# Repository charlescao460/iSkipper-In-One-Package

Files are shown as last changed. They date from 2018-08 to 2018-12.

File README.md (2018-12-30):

iSkipper-In-One-Package
=======================
An integration of Arduino and RFM69HW for an audience response system.
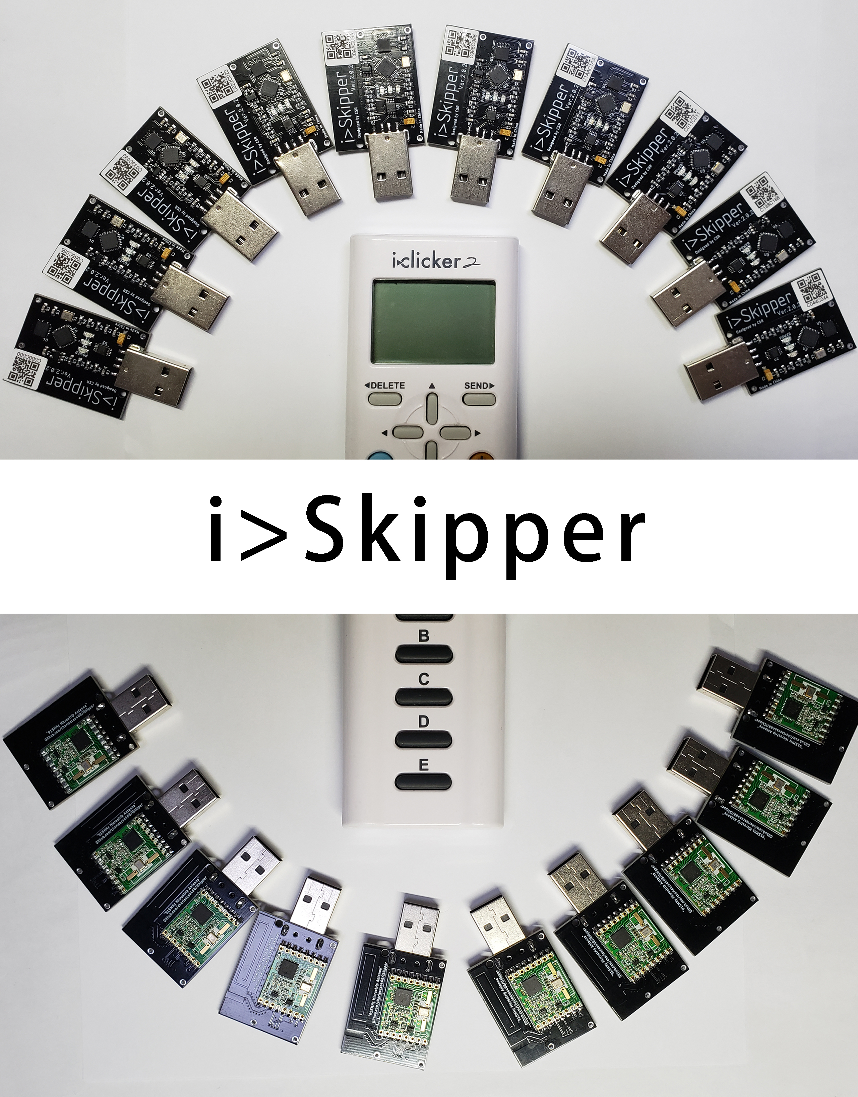
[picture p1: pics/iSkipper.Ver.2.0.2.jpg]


Versions
----
For the hardwares, there are currently two available versions: ***Ver.1.0.2*** and ***Ver.2.0.2***. (The Ver.1.0.0-1.0.1, Ver.2.0.0-2.0.1 are not perfectly useable).

The softwares should be compatible with all versions of hardwares.

### Ver.2.0.2
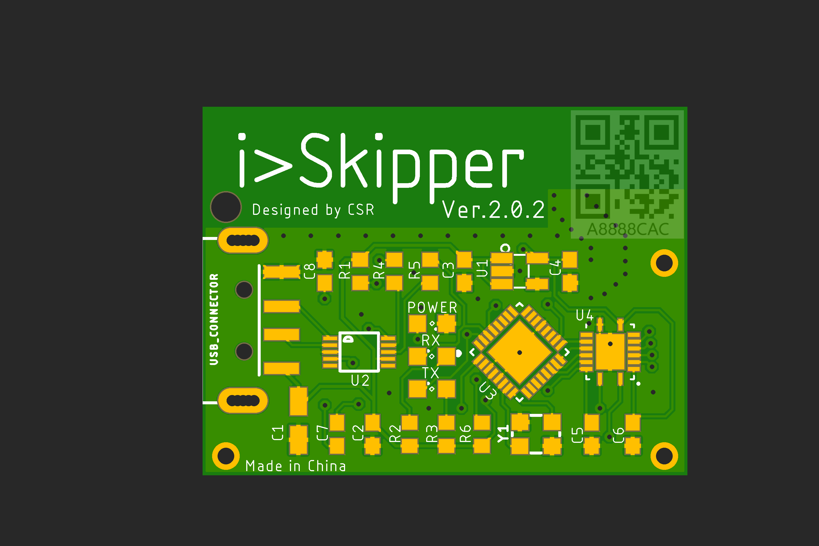
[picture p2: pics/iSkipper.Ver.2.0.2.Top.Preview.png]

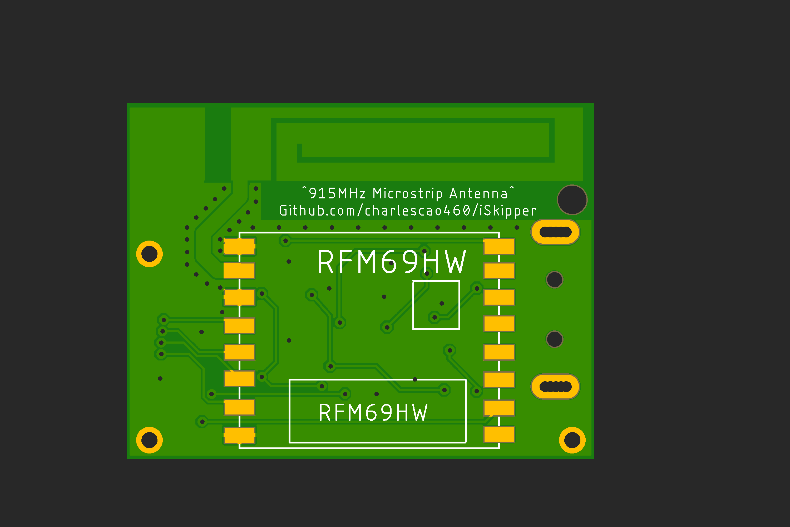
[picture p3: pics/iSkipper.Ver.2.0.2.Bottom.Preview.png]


**Size:** 50mm x 26mm (including USB connector), 35mm x 26mm (without USB connector)

**MCU:** ATmega328P-MU (QFN-32)

**USB to Serial:** CH340E (MSOP-10)

**RF:** RFM69HW

**Level-shifting:** TXB0106RGYR (VQFN-16)

**3.3V power supply:** LP5907MFX-3.3 (SOT23-5)

**Antenna:** patch antenna (theoretically 3dbi gain)

**Resistors/Capacitors:** 0603

The Ver.2.X.X version is designed to minimize board's size, maximize portability and invisibility. Thus, the possibly smallest packages are selected. For example, the patch antenna, QFN-packaged chips, 0603 Resistors/Capacitors are used. Although it still practicable to solder it manually, it would be hard to do so without solder paste. Besides, you would need to burn Arduino's bootloader into ATmega328P-MU before soldering. Burning bootloader would require a QFN-32 dock, or other additional cost.

There are four holes on the board reserved for case installing. If you are going to use screws to install Acrylic case, please notice that the metal screws near the patch antenna would influence antenna's performances.

### Ver.1.0.2
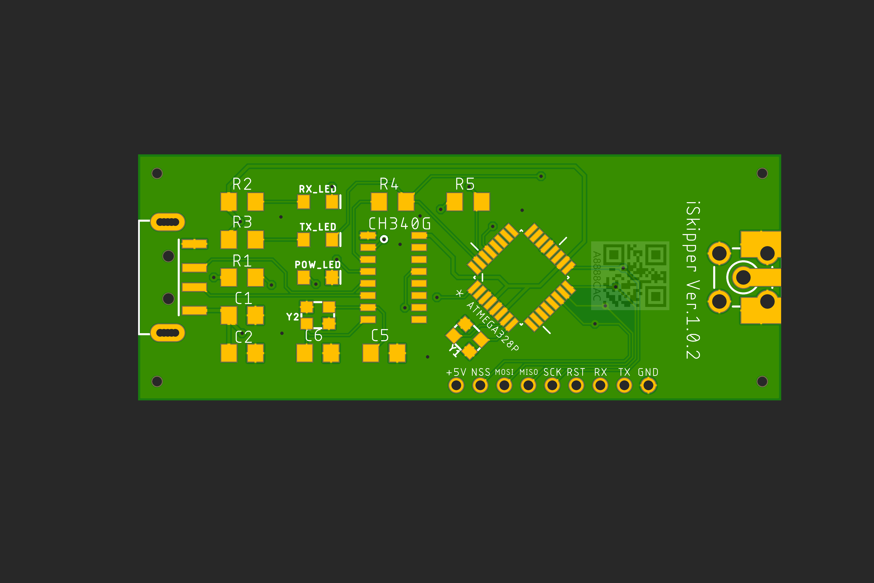
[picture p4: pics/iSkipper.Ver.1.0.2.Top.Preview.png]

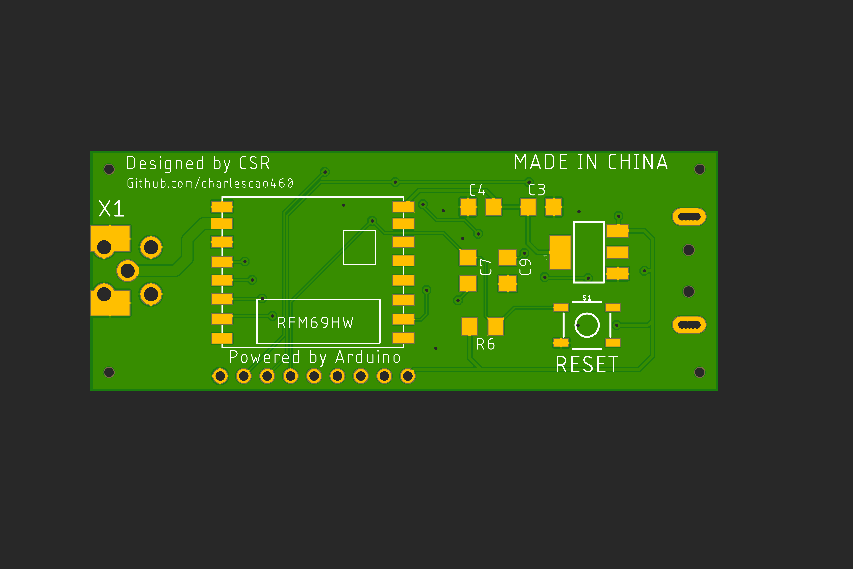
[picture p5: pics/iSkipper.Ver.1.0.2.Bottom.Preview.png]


**Size:** 90mm x 26mm (with connectors), 68mm x 26mm (without connectors)

**MCU:** ATmega328P-AU (QFP-32)

**USB to Serial:** CH340G (SOP-16)

**RF:** RFM69HW

**Level-shifting:** None (but it still work)

**3.3V power supply:** LM1117-3.3 (SOT223) (AMS1117 is also selectable)

**Antenna:** external antenna (with SMA connector)

**Resistors/Capacitors:** 1206

The Ver.1.X.X version is the first design of this project. It is basically a combination of Arduino Nano and RFM69HW. The original goal of this design is make it to be easy-manufactured. Thus, all components are big enough to solder with the normal soldering equipments and materials.

Some useful pin headers are reserved for burning bootloader or debugging. 

This version requires external antenna for better RF performance. The high-gain antennas would improve receiving performances. However, the overall size of this board would then be very big. (And if you are using this in public, the flaring LEDs and long antenna would catch everyone's eyes:) 

Notes
------
ATmega328P is working on 5 voltage, but RFM69HW requires 3.3 voltage. However, shockingly, they are stable and durable in daily use.

Update 2018/07/06: In Ver.2.0.0 design, I added a TXB0106 for level-shifting. So the logic level won't be a problem anymore. But I am still wondering why RFM69HW could work proper under 5.0V. To save money, you could still consider remove TXB0106 in your own disign. 

See also
--------
[iSkipper](https://github.com/wizard97/iSkipper) Original repository that inspired this project.

[iSkipper-Software](https://github.com/charlescao460/iSkipper-Software) 
The softwares (contains Arduino Sketch) designed for these boards.

Disclaimer
----------
**This project is only a special version of Arduino Nano.**

**THIS PROJECT IS NOT DESIGNED TO REPLACE, EMULATE, OR BE COMPATIBLE WITH ANY SPECIFIC PRODUCT OF ANY COMPANY.**

**ALL THE PICTURES AND DOCUMENTS OF THIS PROJECT DO NOT IMPLY ANY SPECIFIC USE OF THIS PROJECT.**

**CONTRIBUTORS OF THIS PROJECT ARE FREE OF RESPONSIBILITY OF ANY IMPROPER USE OF THIS PROJECT.**

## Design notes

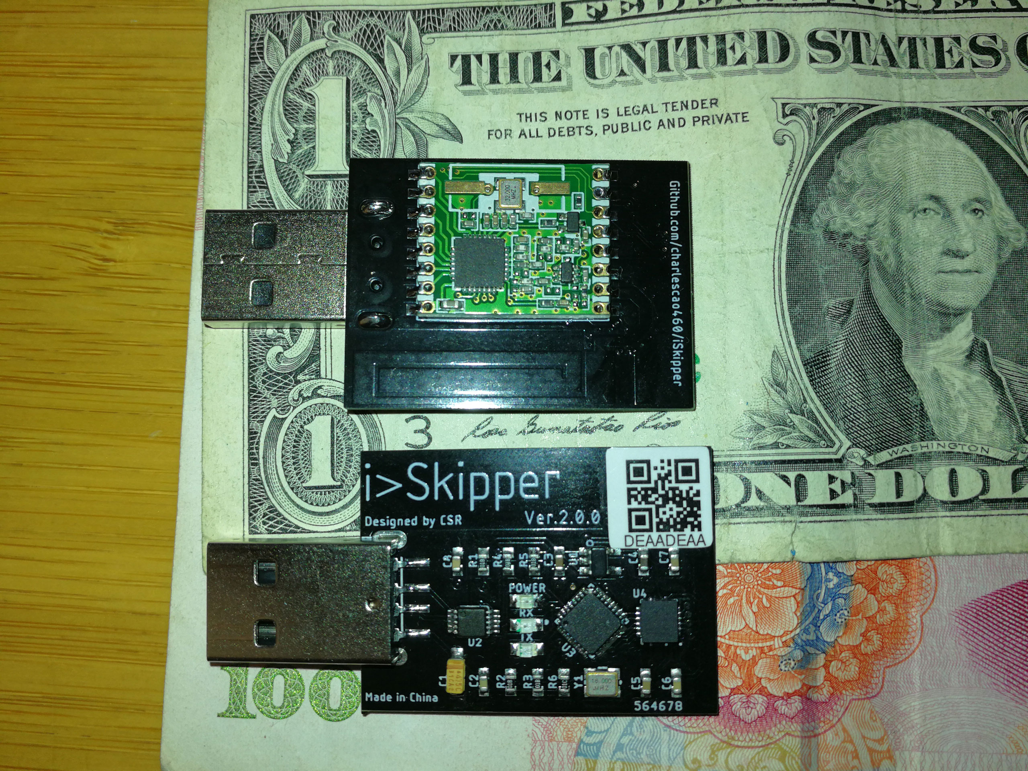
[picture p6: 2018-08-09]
pics/Ver2.0.0.Small.Size.jpg

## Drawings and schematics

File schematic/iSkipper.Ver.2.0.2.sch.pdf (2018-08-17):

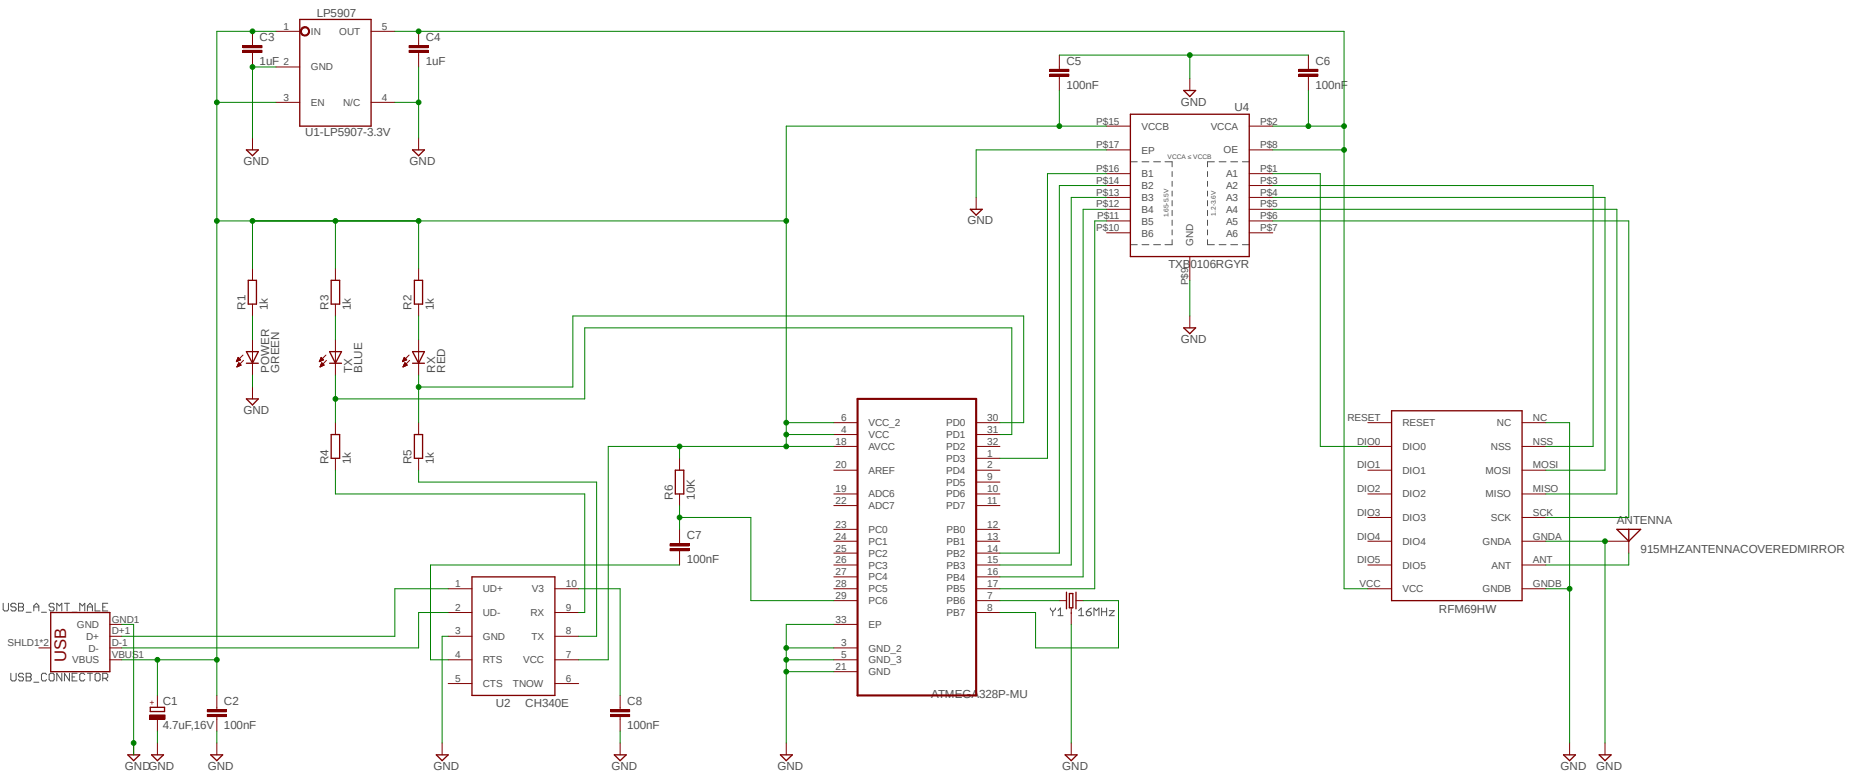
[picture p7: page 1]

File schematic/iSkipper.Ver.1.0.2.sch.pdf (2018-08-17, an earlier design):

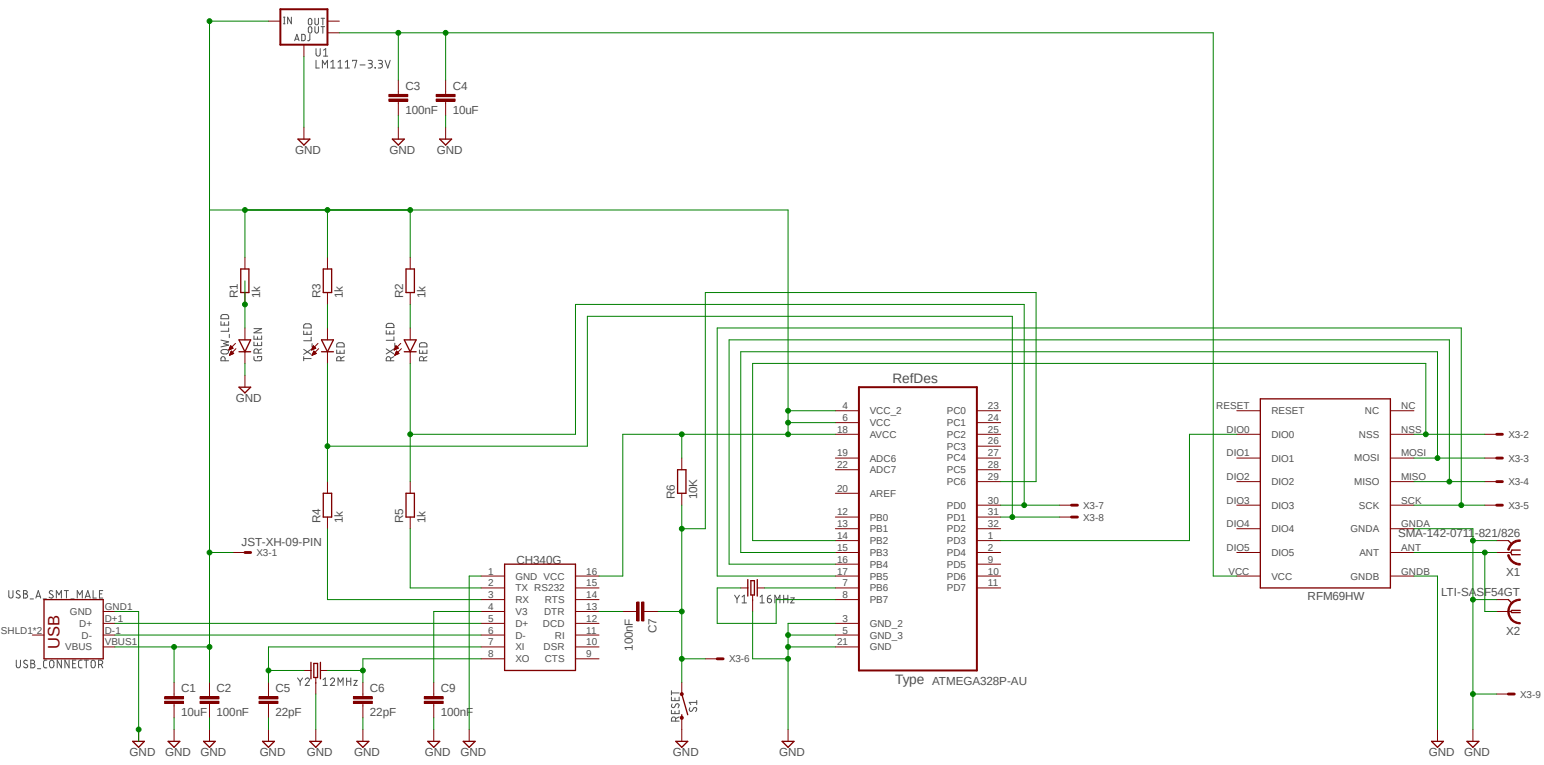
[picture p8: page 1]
Type ATMEGA328P-AU; GND GND GND; GND; GND¹k; RFM69HW ¹k; GND¹⁰K; GND GND; SMA-142-0711-821/826; LTI-SASF54GT; VCC_2 4 VCC 6 AVCC 18; ADC6 19 ADC7 22; AREF 20; GND_2 3 GND_3 5 GND 21; 11 RefDes; VBUS; VBUS1; GND1; SHLD1*2; GND 1 TX 2 RX 3 V3 4 D+ 5 D- 6 XI 7; CTS; DSR; 11 DCD; 12 DTR; 13 RTS; 15 VCC; RESET RESET; DIO0 DIO0; DIO1 DIO1; DIO2 DIO2; DIO3 DIO3; DIO4 DIO4; DIO5 DIO5; VCC VCC; GNDB; ANT; GNDA; SCK; MISO; MOSI; NSS; X3-9 USB

JST-XH-09-PIN

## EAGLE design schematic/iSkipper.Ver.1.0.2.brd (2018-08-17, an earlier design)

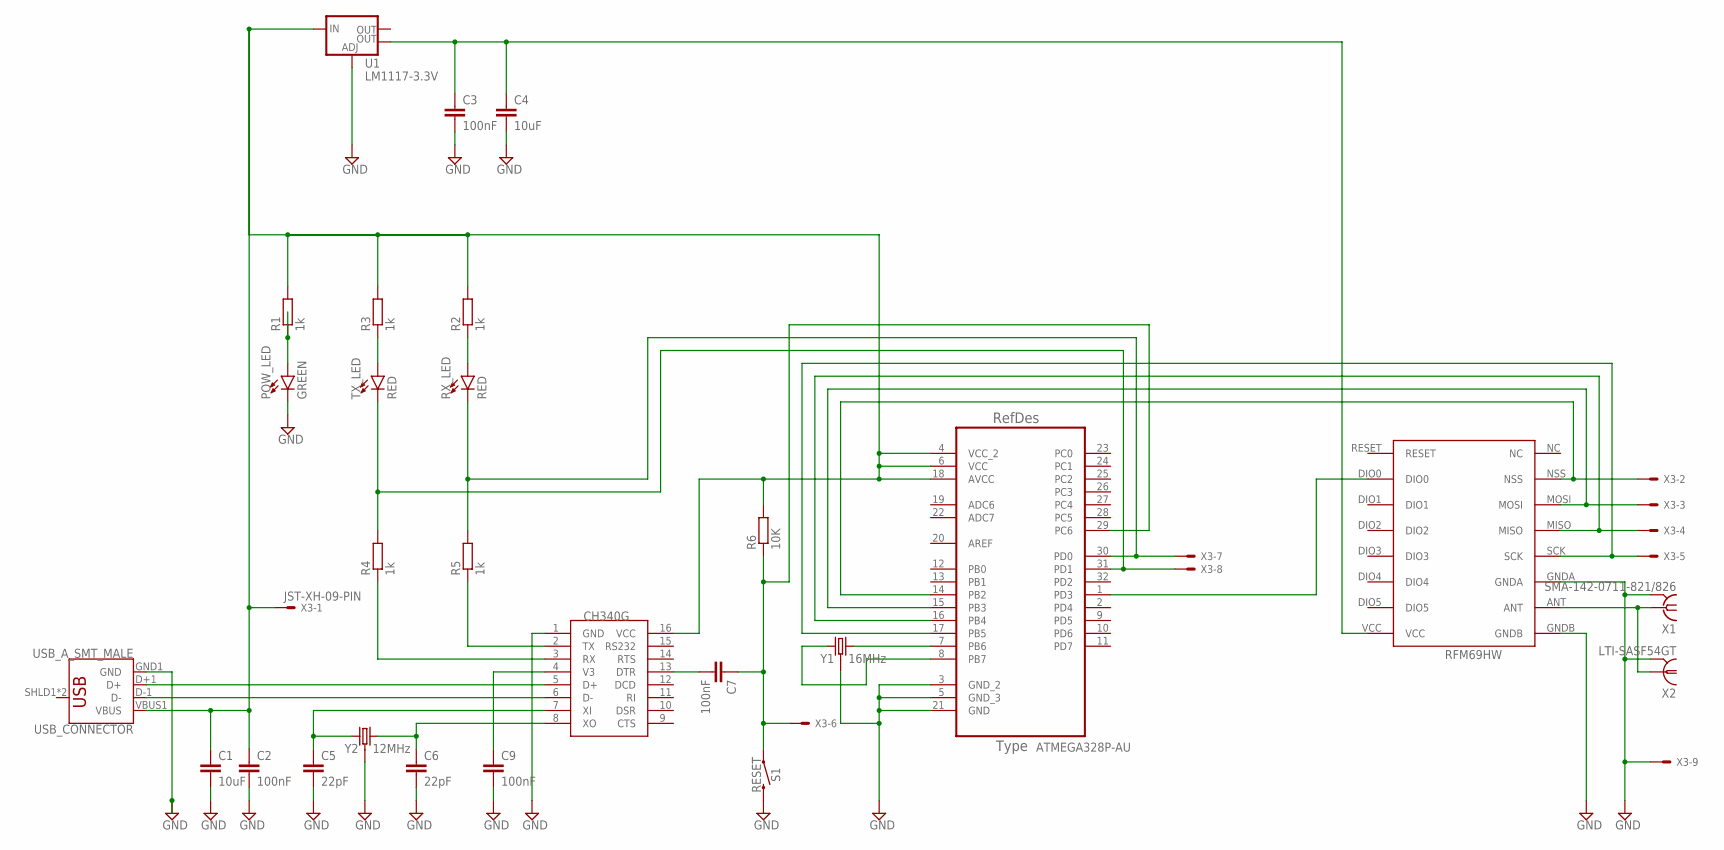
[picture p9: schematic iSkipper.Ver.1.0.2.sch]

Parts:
ATMEGA328P: ATMEGA328P-AU; QFP80P900X900X120-32N
C1, C4: 10uF; C1206
C2, C3, C7, C9: 100nF; C1206
C5, C6: 22pF; C1206
POW_LED: GREEN; LED-1206
R1, R2, R3, R4, R5: 1k; R1206
R6: 10K; R1206
RFM69HW: RFM69HW; RFM
RX_LED: RED; LED-1206
S1: RESET; TACTILE_SWITCH_SMD_5.2MM
TX_LED: RED; LED-1206
U1: LM1117-3.3V; SOT223
U$1: CH340G; SOIC16
USB_CONNECTOR: USB_A_SMT_MALE; USB-A-SMT-MALE
X1: SMA-142-0711-821/826; J502-ND-142-0711-821/826
X2: LTI-SASF54GT
X3: JST-XH-09-PIN; JST-XH-09-PACKAGE-ROUND-PAD-NO-SILK
Y1: 16MHz; CRYSTAL-SMD-3.2X2.5MM
Y2: 12MHz; CRYSTAL-SMD-3.2X2.5MM

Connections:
GND: ATMEGA328P.3 (GND_2), ATMEGA328P.5 (GND_3), ATMEGA328P.21 (GND), C1.2, C2.2, C3.2, C4.2, C5.2, C6.2, C9.2, POW_LED.C, RFM69HW.GNDA, RFM69HW.GNDB, S1.3 (2), U1.1 (ADJ), U$1.1 (GND), USB_CONNECTOR.GND1 (GND), X1.G@1 (2), X1.G@2 (2), X1.G@3 (2), X1.G@4 (2), X2.2, X2.3 (2), X2.4 (2), X2.5 (2), X3.9, Y1.2 (3), Y1.4 (3), Y2.2 (3), Y2.4 (3)
unnamed: ATMEGA328P.7 (PB6), Y1.3 (2)
unnamed: ATMEGA328P.8 (PB7), Y1.1
unnamed: ATMEGA328P.4 (VCC_2), ATMEGA328P.6 (VCC), ATMEGA328P.18 (AVCC), C1.1, C2.1, R1.2, R2.2, R3.2, R6.2, U1.3 (IN), U$1.16 (VCC), USB_CONNECTOR.VBUS1 (VBUS), X3.1
unnamed: U$1.5 (D+), USB_CONNECTOR.D+1 (D+)
unnamed: C3.1, C4.1, RFM69HW.VCC, U1.4 (OUT)
unnamed: POW_LED.A, R1.1
unnamed: R3.1, TX_LED.A
unnamed: U$1.6 (D-), USB_CONNECTOR.D-1 (D-)
unnamed: R2.1, RX_LED.A
unnamed: R5.1, U$1.2 (TX)
unnamed: C6.1, U$1.8 (XO), Y2.3 (2)
unnamed: C5.1, U$1.7 (XI), Y2.1
unnamed: R4.1, U$1.3 (RX)
unnamed: ATMEGA328P.31 (PD1), R4.2, TX_LED.C, X3.8
unnamed: ATMEGA328P.30 (PD0), R5.2, RX_LED.C, X3.7
unnamed: C7.2, U$1.13 (DTR)
unnamed: ATMEGA328P.29 (PC6), C7.1, R6.1, S1.1, X3.6
unnamed: RFM69HW.ANT, X1.1, X2.1
unnamed: C9.1, U$1.4 (V3)
unnamed: ATMEGA328P.17 (PB5), RFM69HW.SCK, X3.5
unnamed: ATMEGA328P.1 (PD3), RFM69HW.DIO0
unnamed: ATMEGA328P.14 (PB2), RFM69HW.NSS, X3.2
unnamed: ATMEGA328P.16 (PB4), RFM69HW.MISO, X3.4
unnamed: ATMEGA328P.15 (PB3), RFM69HW.MOSI, X3.3

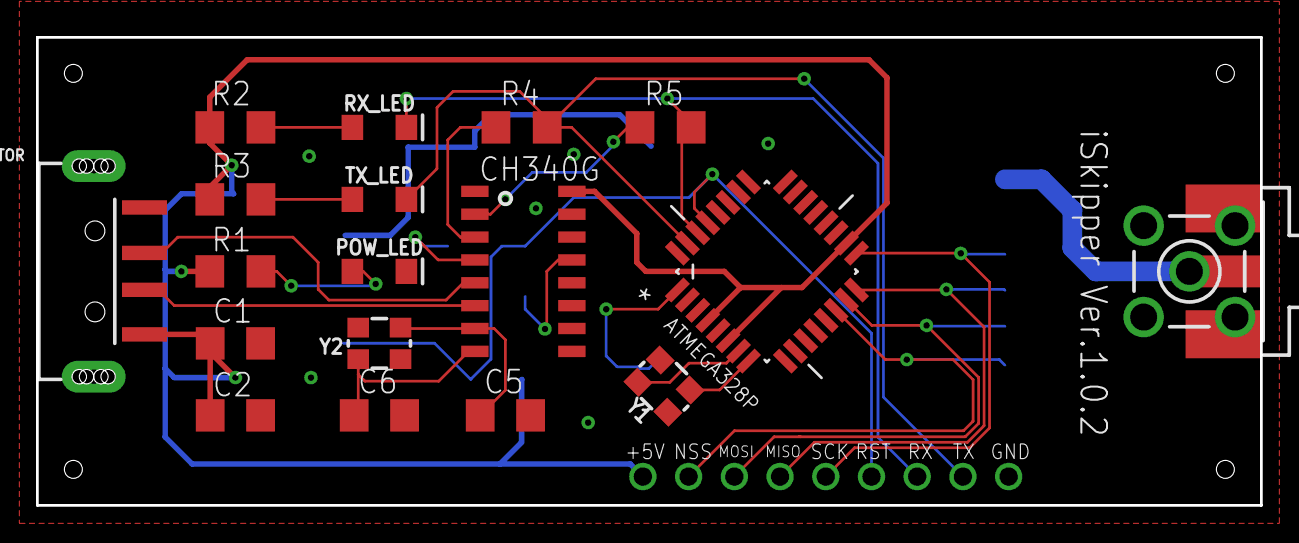
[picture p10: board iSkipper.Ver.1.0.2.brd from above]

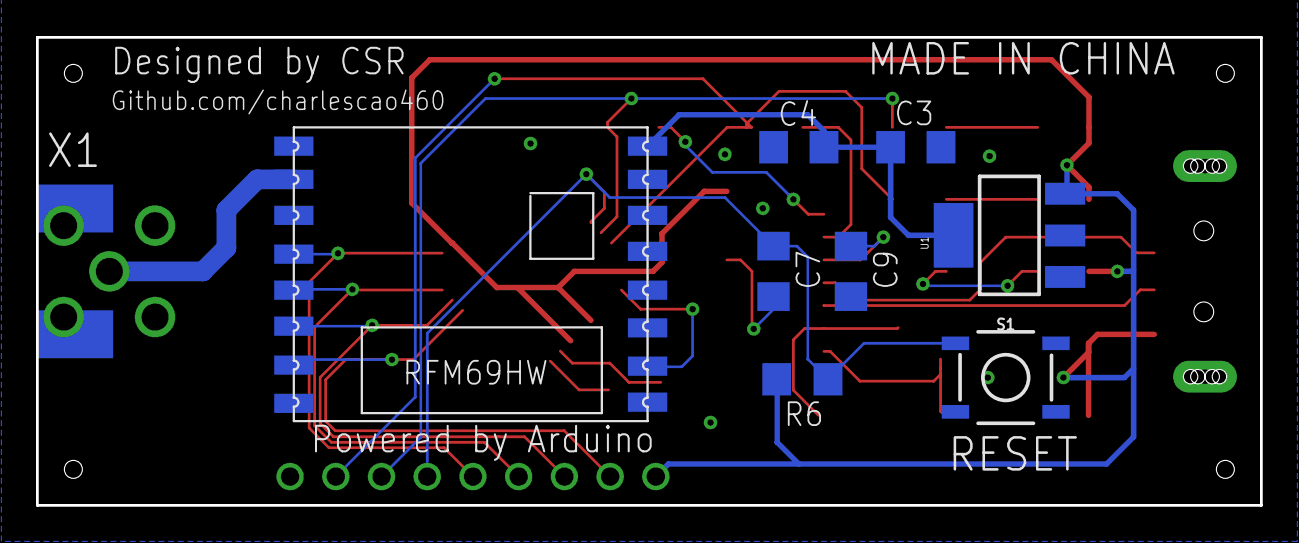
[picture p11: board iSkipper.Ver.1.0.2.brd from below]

Board: 2 copper layers, 68.0 x 26.0 mm, 28 parts (8 on the bottom side), 25 nets.

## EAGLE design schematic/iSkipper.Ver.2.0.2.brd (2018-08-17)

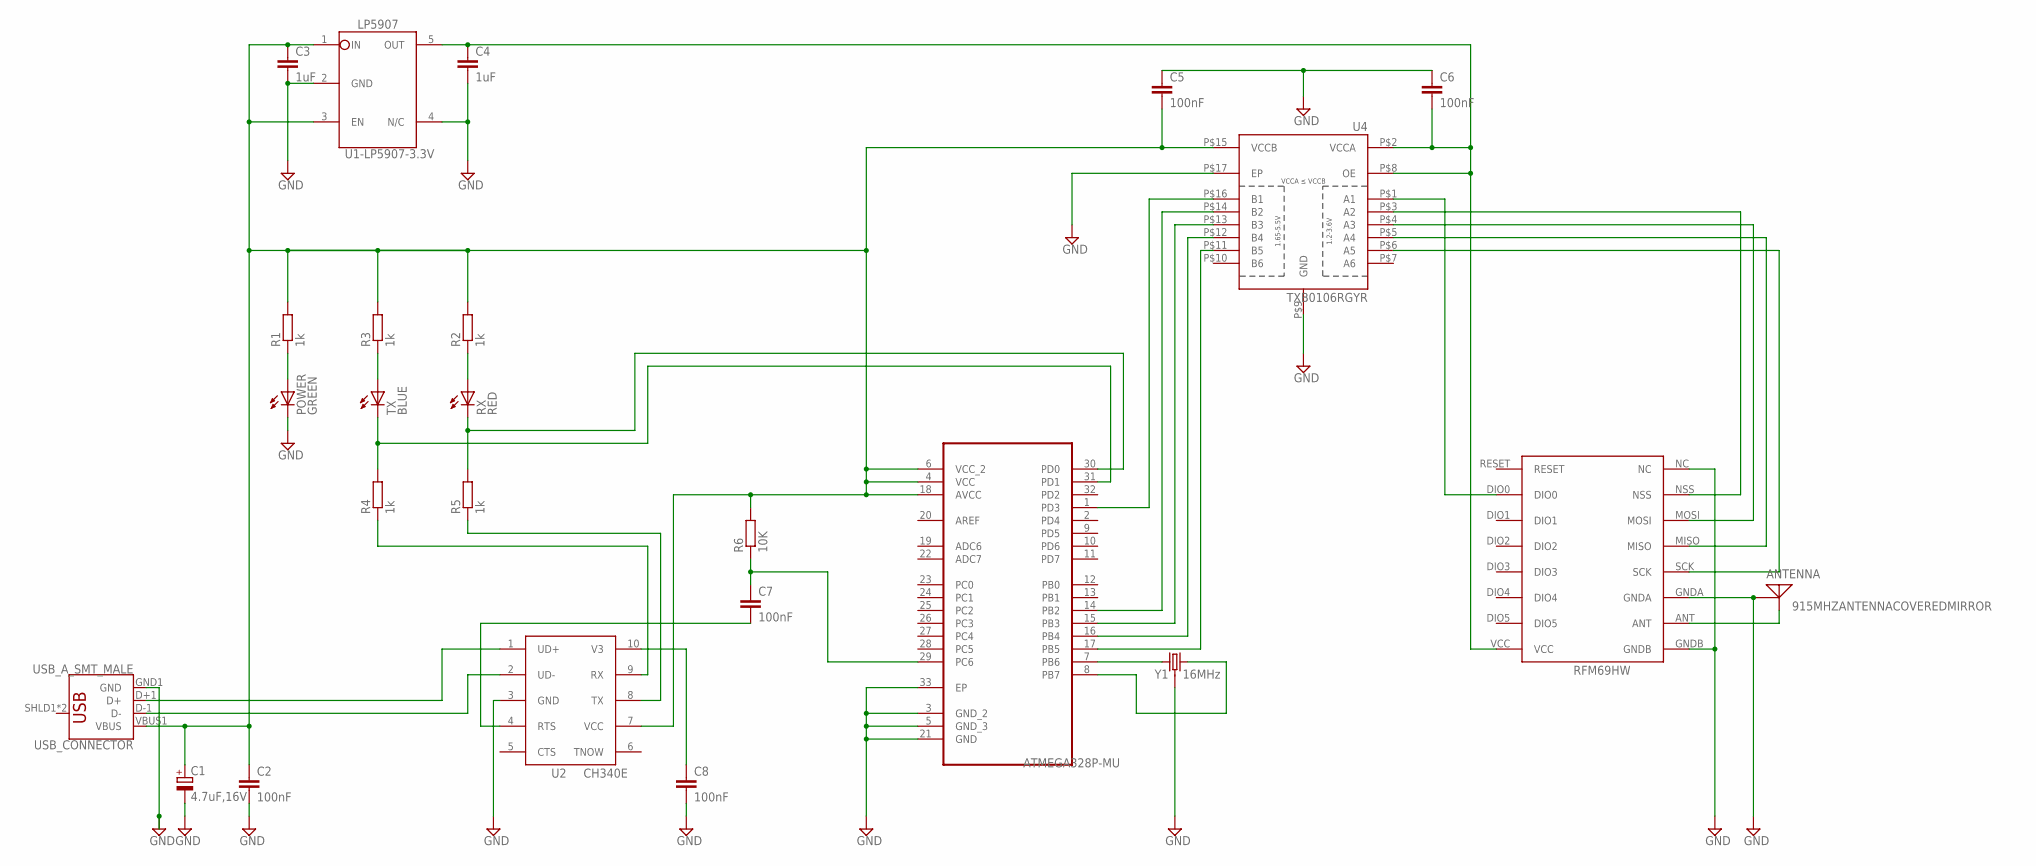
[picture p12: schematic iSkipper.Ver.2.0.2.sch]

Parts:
ANTENNA: 915MHZANTENNACOVEREDMIRROR; COVERED-MIRROR
C1: 4.7uF,16V; CT3216
C2, C5, C6, C7, C8: 100nF; C0603
C3, C4: 1uF; C0603
POWER: GREEN; SML0805
R1, R2, R3, R4, R5: 1k; R0603
R6: 10K; R0603
RFM69HW: RFM69HW; RFM
RX: RED; SML0805
TX: BLUE; SML0805
U2: CH340ESMD; MSOP10
U4: TXB0106RGYR; VQFN-16
U$1: U1-LP5907-3.3V; SOT-23
U$3: ATMEGA328P-MU; QFN50P500X500X100-33N
USB_CONNECTOR: USB_A_SMT_MALE; USB-A-SMT-MALE
Y1: 16MHz; CRYSTAL-SMD-3.2X2.5MM

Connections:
GND: ANTENNA.P$2 (GND), C1.-, C2.2, C3.2, C4.2, C5.1, C6.1, C8.2, POWER.C, RFM69HW.GNDA, RFM69HW.GNDB, RFM69HW.NC, U2.3 (GND), U4.P$9 (GND), U4.P$17 (EP), U$1.2 (GND), U$1.4 (N/C), U$3.3 (GND_2), U$3.5 (GND_3), U$3.21 (GND), U$3.33 (EP), USB_CONNECTOR.GND1 (GND), Y1.2 (3), Y1.4 (3)
unnamed: U$3.7 (PB6), Y1.1
unnamed: U$3.8 (PB7), Y1.3 (2)
unnamed: C1.+, C2.1, C3.1, C5.2, R1.2, R2.2, R3.2, R6.2, U2.7 (VCC), U4.P$15 (VCCB), U$1.1 (IN), U$1.3 (EN), U$3.4 (VCC), U$3.6 (VCC_2), U$3.18 (AVCC), USB_CONNECTOR.VBUS1 (VBUS)
unnamed: C7.2, U2.4 (RTS)
unnamed: U2.1 (UD+), USB_CONNECTOR.D+1 (D+)
unnamed: C4.1, C6.2, RFM69HW.VCC, U4.P$2 (VCCA), U4.P$8 (OE), U$1.5 (OUT)
unnamed: POWER.A, R1.1
unnamed: R3.1, TX.A
unnamed: U2.2 (UD-), USB_CONNECTOR.D-1 (D-)
unnamed: R2.1, RX.A
unnamed: R5.1, U2.8 (TX)
unnamed: C8.1, U2.10 (V3)
unnamed: R4.1, U2.9 (RX)
unnamed: U4.P$14 (B2), U$3.14 (PB2)
unnamed: R4.2, TX.C, U$3.31 (PD1)
unnamed: R5.2, RX.C, U$3.30 (PD0)
unnamed: U4.P$16 (B1), U$3.1 (PD3)
unnamed: C7.1, R6.1, U$3.29 (PC6)
unnamed: ANTENNA.P$1 (SIGNAL), RFM69HW.ANT
unnamed: RFM69HW.SCK, U4.P$6 (A5)
unnamed: RFM69HW.DIO0, U4.P$1 (A1)
unnamed: RFM69HW.NSS, U4.P$3 (A2)
unnamed: RFM69HW.MISO, U4.P$5 (A4)
unnamed: RFM69HW.MOSI, U4.P$4 (A3)
unnamed: U4.P$11 (B5), U$3.17 (PB5)
unnamed: U4.P$12 (B4), U$3.16 (PB4)
unnamed: U4.P$13 (B3), U$3.15 (PB3)

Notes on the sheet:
CH340E

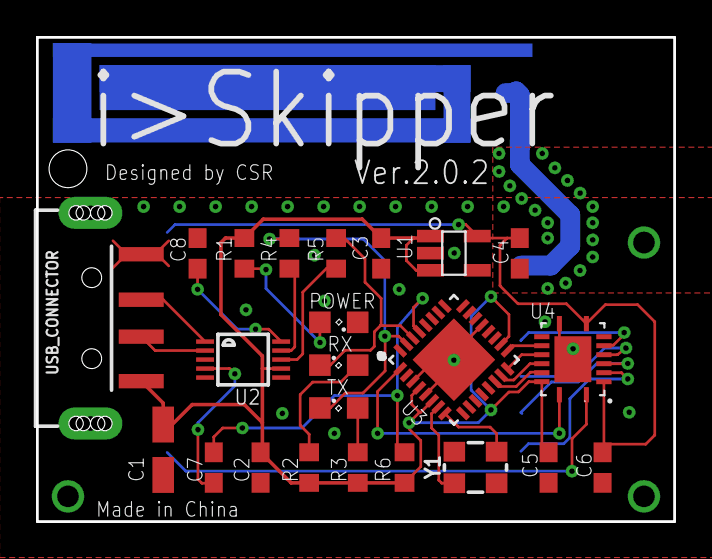
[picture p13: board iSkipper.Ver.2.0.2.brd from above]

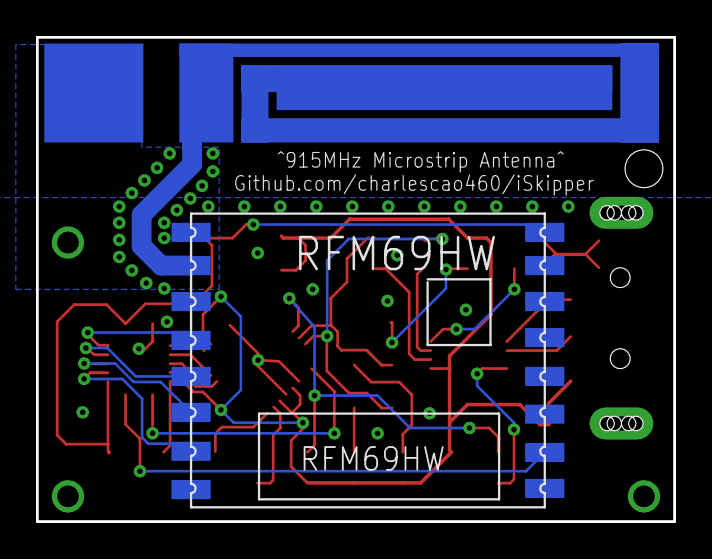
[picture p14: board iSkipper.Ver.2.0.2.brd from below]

Board: 2 copper layers, 35.4 x 26.9 mm, 25 parts (2 on the bottom side), 28 nets.

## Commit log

2018-08-09 Create Repository
    [iSkipper.Ver.1.0.1.sch, iSkipper.Ver2.0.1.brd, iSkipper.Ver2.0.1.sch]
2018-08-17 Update PCB files
    [iSkipper.Ver.1.0.2.brd, iSkipper.Ver.1.0.2.sch, iSkipper.Ver.2.0.2.brd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]
2018-08-17 Remove corrupted designs
    [iSkipper.Ver.1.0.1.sch, iSkipper.Ver2.0.1.brd, iSkipper.Ver2.0.1.sch]

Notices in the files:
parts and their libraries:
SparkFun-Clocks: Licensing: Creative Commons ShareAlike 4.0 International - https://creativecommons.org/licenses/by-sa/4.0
